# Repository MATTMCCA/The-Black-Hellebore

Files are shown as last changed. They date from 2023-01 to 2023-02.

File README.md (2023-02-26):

# The Black Hellebore

### The Black Hellebore, RK61 PCB (Redesign)

What to do with the most popular keyboard on amazon? Reverse engineer it obviously! QMK powered PCB for the RK61. The design uses actual STM32 IC.

**The PCB design in this repository is not intended for commercial sales**

---

* **[Watch the Hand Assembly Video : PART I](https://youtu.be/cKcGKz691ds)**
* **[Watch the Hand Assembly Video : PART II](https://youtu.be/HiYZSflaqEU)**
* **[Watch the Solder Joint Repair Video : PART III](https://youtu.be/VTa4d78aN-c)**
* **[Watch Load Switch Demo](https://youtu.be/AGMwodDWTGg)**

---

## Understanding USB 2.0 Power Spec.

[In general, the specifications for a USB 1.0 and 2.0 standard downstream port, delivers up to 500 mA or 0.5A.](https://resources.pcb.cadence.com/blog/2020-what-are-the-maximum-power-output-and-data-transfer-rates-for-the-usb-standards) With this statement it becomes clear, the max power available to any system using a **type A** connector is 500mA. If the host implements brick-wall current limiting, and the device attached attempts to draw more than 2.5Watts, the current limiter will start dissipating heat. This dissipated heat can lead to thermal shutdown and or possible damage to the host system.

Building on this further, it makes since why most USB type A ports provide more than 500mA. Its to prevent the host current limiting circuit from going into thermal shutdown.

*because I don't have mechanisms in place on the device to handle power negotiation, I'm not assuming the host port can supply more than 2.5Watts of power*

*I would also like to briefly point out that the STM32L412 only has USB Full speed 2.0. It seems kinda silly to use a USB 3.0 connector, when both power and data are USB gen 2.0, admittedly it is nice not worrying about the cable orientation.*

## Part Notes

* CC1 & CC2 Resistors should be 1% not 5%.
* SK6803MINI-E is recommended over SK6812MINI-E.

## Project State

* My Digikey order has arrived.
* Waiting on PCB's (ETA Jan 20th) - Arrived 1-8-2023
* Finished final hand assembly (1-21-2023)
* Tested and confirmed working with QMK and VIA.
* Figured out all of the things (duration, too long...)
* Board Revision Pending.... 
* Board Rev Finished (1-28-2023, sent to fab)
* Waiting on PCB's (ETA 2-10-2023) - Arrived 2-6-2023
* Started finial hand assembly (2-11-2023) (see project log below) 
* Board Revision Pending.... 
* Sent version 1.2.1 to fab
* Got 1.2.1 from fab, all is well
* Inadvertently filmed a time laps (2-22-2023)
* non time laps video pending.
* Project done, the PCB works perfect!

*My fancy USB cable reported a 1.5Watt power draw before the load switch went into auto recover. This tells me, my current limit is actually set to around 300mA, not 445mA as calculated.*

# Project Log

### Epic Fail
I began soldering the MCU and current switch IC and everything was going smooth. After I soldered the first row of LED's, I applied power and nothing happened. It was at this point I began to suspect my clever feedback network, sure enough I was getting zero volts on the output. 

Without a second thought, I depopulated the retry network and tested the circuit again. Same result, no RGB. I started measuring the RGB PWM of the MCU with my scope, I was getting no PWM output, I thought "Great! I zapped my STM32". I removed power from the circuit, then started poking around with my meter, come to find out, every RGB LED was shorted to ground.

I removed all of the RGB LED's and checked the first row of pads, no shorts. I replaced the LED, and there's a short!! I tried 5 different LED's before I noticed it..... JLCPCB milled into the ground pore copper!!!! see **001.bmp & 002.bmp**. When the LED is soldered, a short occurs between the pin and the ground plane. I'm wondering if this issue affected previous revs.

I'm going to add a keep out area around the RGB LED's to prevent my future revision from suffering the same fate as 1.2.0. .....that's another punch to the wallet, I'm not making that mistake again.... I also expected better milling from JLCPCB.

### A Small Win
From what I can tell, the auto retry feedback network on the ```AP22653AW6-7``` worked as designed. When a fault occurs, oscillation takes place in the feedback network. When the short is removed the enable signal stays high, it was neat to see it in action for the first time on the scope.

---

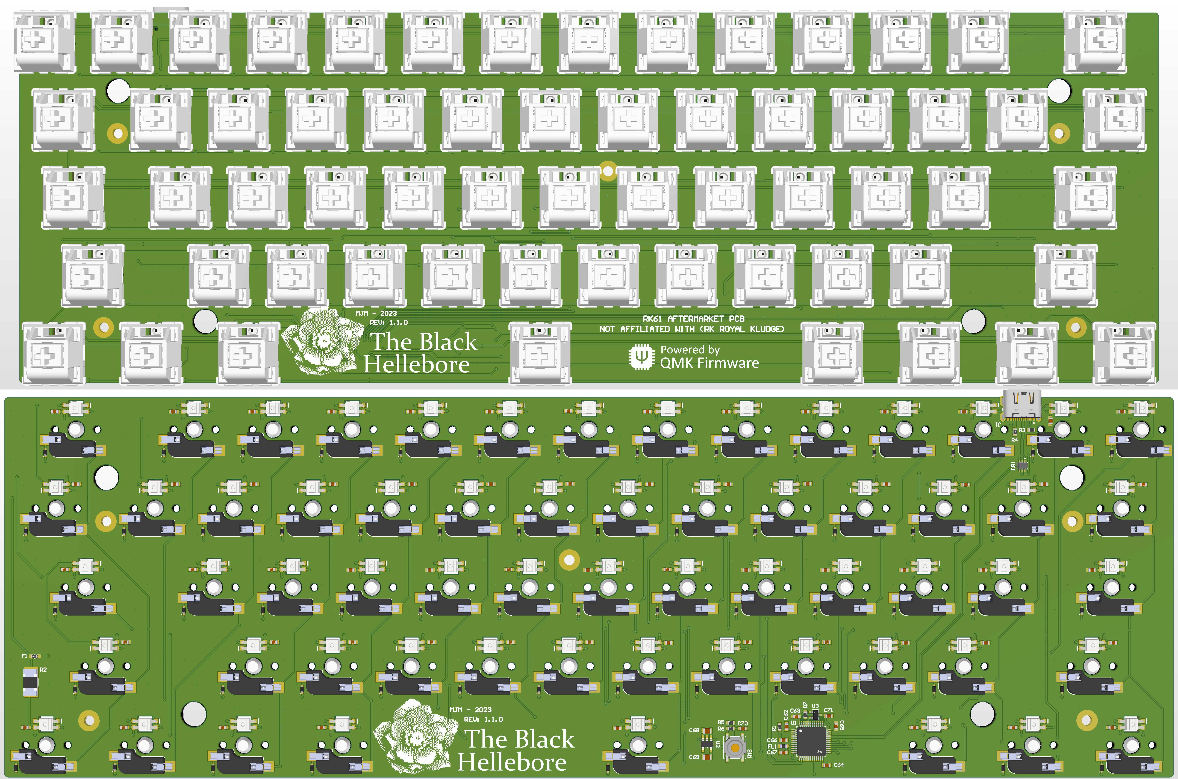
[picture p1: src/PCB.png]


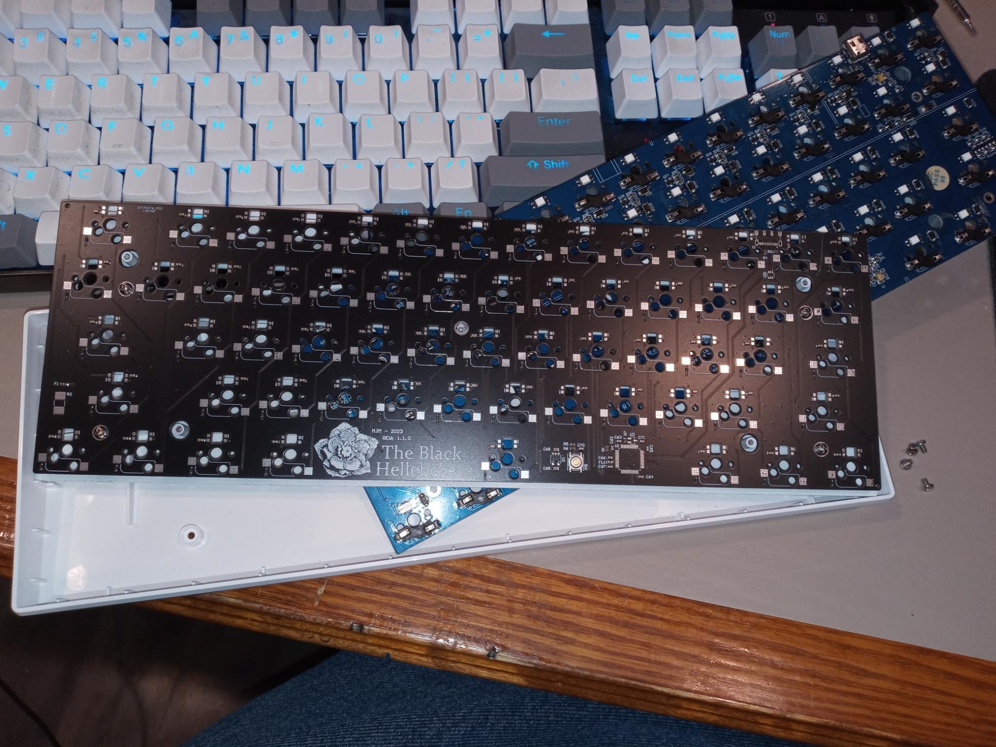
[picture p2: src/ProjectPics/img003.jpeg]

 
# View All Project Files Online
 
https://www.altium.com/viewer/

---
 
MIT licensed keyboard.

"Buy Me A Coffee" (https://www.buymeacoffee.com/mccardlema3)

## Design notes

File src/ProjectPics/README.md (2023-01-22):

# The Black Hellebore

### The Black Hellebore, RK61 PCB (Clone)

* IMG001 (1000x switch sockets and 1000x RGB LEDS)
* IMG002 (Digikey Parts Order)
* IMG003 (JLC PCB's arrived)
* IMG004 (preliminary aftermarket fit)
* IMG005 (fully assembled PCB attached to RK61 plate)
* IMG006 (fully assembled PCB in RK61 case)
* IMG007 (playing with RGB)

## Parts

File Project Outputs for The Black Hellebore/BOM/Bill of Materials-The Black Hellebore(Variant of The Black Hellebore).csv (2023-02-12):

Comment | Description | Designator | Footprint | LibRef | Quantity
CC0603JRX7R9BB104 | 0603 0.1 uF 50 V ±5 % Tolerance X7R SMT Multilayer Ceramic Capacitor | C1, C2, C3, C4, C5, C6, C7, C8, C9, C10, C11, C12, C13, C14, C15, C16, C17, C18, C19, C20, C21, C22, C23, C24, C25, C26, C27, C28, C29, C30, C31, C32, C33, C34, C35, C36, C37, C38, C39, C40, C41, C42, C43, C44, C45, C46, C47, C48, C49, C50, C51, C52, C53, C54, C55, C56, C57, C58, C59, C60, C61, C62, C63, C64, C65, C66, C67, C69, C70, C71 | FP-CC0603-DA-MFG | CMP-004-000009-6 | 70
GRM21BR71A106KA73K | Cap Ceramic 10uF 10V X7R 10% Pad SMD 0805 125C T/R | C68, C72 | FP-GRM21B-0_15-MFG | CMP-004-000013-3 | 2
CC0603JRX7R7BB105 | Cap Ceramic 1uF 16V X7R 5% SMD 0603 125°C Paper T/R | C73 | FP-CC0603-DA-MFG | CMP-004-000010-4 | 1
RCLAMP0504FBTCT | ESD Suppressor TVS Quad Uni-Dir 30kV 6-Pin SC-70 T/R | CR1 | SC70_RCLAMP_SEM | CMP-138-000000-2 | 1
RB520S30T5G | RB520S30T5G - 30 V 200 mA Surface Mount Schottky Diode - SOD-523 | D1, D2, D3, D4, D5, D6, D7, D8, D9, D10, D11, D12, D13, D14, D15, D16, D17, D18, D19, D20, D21, D22, D23, D24, D25, D26, D27, D28, D29, D30, D31, D32, D33, D34, D35, D36, D37, D38, D39, D40, D41, D42, D43, D44, D45, D46, D47, D48, D49, D50, D51, D52, D53, D54, D55, D56, D57, D58, D59, D60, D61, D62 | ONSC-SOD-523-2-502-01_V | CMP-070-000008-4 | 62
0603L010YR | 15VDC 100mA | F1 | FP-0603L-MFG | CMP-096-000003-1 | 1
BLM18AG601SN1D | 600 Ohms @ 100MHz 1 Ferrite Bead 0603 _1608 Metric_ 500mA 380mOhm | FL1 | BEADC1608X95N | CMP-032-000000-2 | 1
DX07S016JA1R1500 | Connector, USB Type C Receptacle, 1500 piece reel, 16 Pin Version | J1 | FP-DX07S016JA1R1500-MFG | CMP-042-000007-2 | 1
RMCF0603JT10K0 | Res Thick Film 0603 10K Ohm 5% 1/10W ±100ppm/°C Molded SMD SMD Paper T/R | R1, R2, R5, R7 | FP-RMCF0603-MFG | CMP-012-000009-4 | 4
RMCF0603JT5K10 | Res Thick Film 0603 5.1K Ohm 5% 1/10W ±200ppm/°C Molded SMD Paper T/R | R3, R4 | FP-RMCF0603-MFG | CMP-012-000000-2 | 2
RMCF0603JT1K00 | Res Thick Film 0603 1K Ohm 5% 1/10W ±200ppm/°C Molded SMD Paper T/R | R6 | FP-RMCF0603-MFG | CMP-000007-3 | 1
RMCF0603JT100K | Res Thick Film 0603 100K Ohm 5% 1/10W ±200ppm/°C Molded SMD Paper T/R | R8 | FP-RMCF0603-MFG | CMP-000004-8 | 1
RMCF0603FT68K0 | Res Thick Film 0603 68K Ohm 1% 0.1W(1/10W) ±100ppm/C Pad SMD Automotive T/R | R9 | FP-RMCF0603-MFG | CMP-012-000019-2 | 1
PTS526SK15SMTR2LFS | Switch Tactile N.O. SPST Round Button Gull Wing 0.05A 12VDC 200000Cycles 2.55N SMD T/R | SW1 | FP-PTS526SK15SMTR2LFS-MFG | CMP-014-000000-1 | 1
STM32L412CBT6 | STMICROELECTRONICS - STM32L412CBT6 - ARM MCU, STM32 Family STM32L4 Series Microcontrollers, ARM Cortex-M4, 32bitu, 80 MHz, 128 KB, 40 KB | U1 | FP-LQFP48-5B-MFG | CMP-148-000005-1 | 1
AP2139AK-3.3TRG1 | IC REG LDO 3.3V 0.25A SOT25 | U2 | DBV0005A-IPC_A | CMP-140-000002-1 | 1
MIC803-26D4VC3-TR | 3-Pin Microprocessor Supervisor Circuit w/ Open-Drain Reset Output | U3 | SC-70_C3_MCH | CMP-136-000000-2 | 1
AP22653AW6-7 | PRECISION ADJUSTABLE CURRENT-LIMITED POWER SWITCHES, -40 to 85°C pF, RoHS | U4 | SOT26-A1_DIO | CMP-148-000002-2 | 1

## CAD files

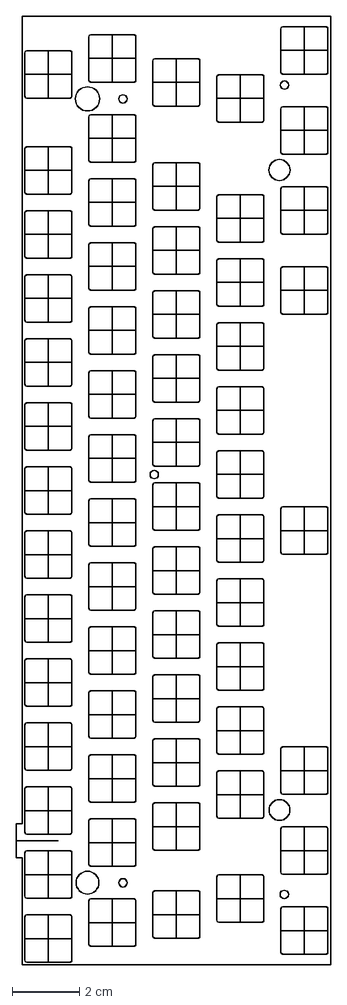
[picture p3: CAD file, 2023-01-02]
Factory_19.05mm/Fixed-Factory-Template.dxf
9.35 x 28.2 cm

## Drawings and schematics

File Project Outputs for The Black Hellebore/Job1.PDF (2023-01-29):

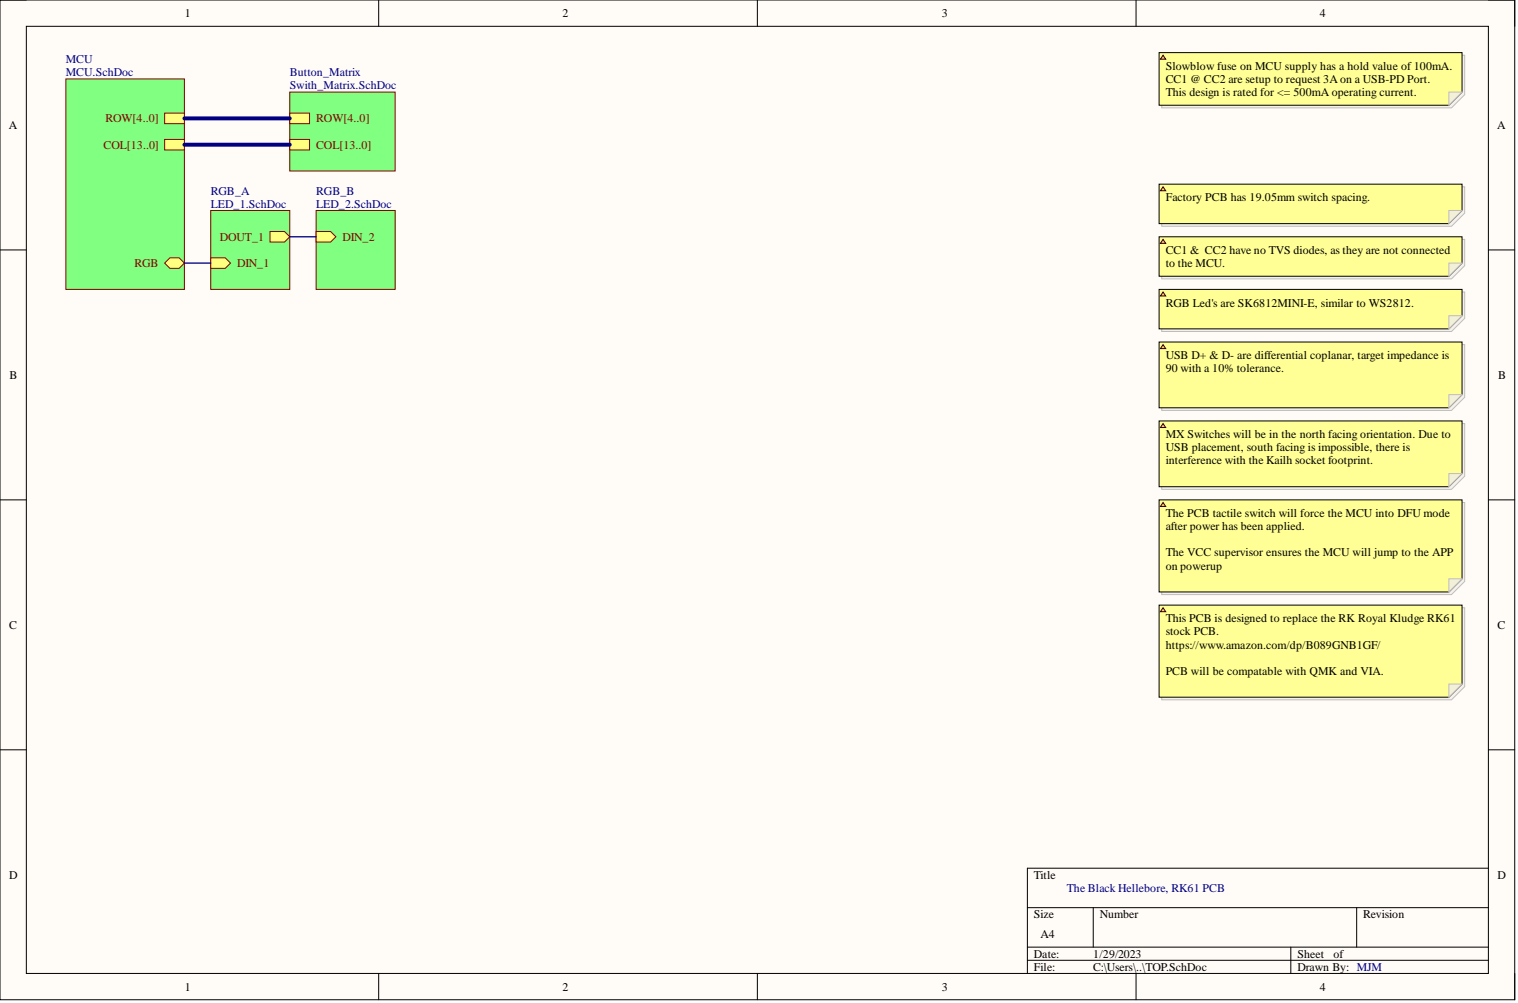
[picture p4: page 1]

Slowblow fuse on MCU supply has a hold value of 100mA.
CC1 @ CC2 are setup to request 3A on a USB-PD Port.
This design is rated for <= 500mA operating current.

Factory PCB has 19.05mm switch spacing.

CC1 & CC2 have no TVS diodes, as they are not connected
to the MCU.

RGB Led's are SK6812MINI-E, similar to WS2812.

USB D+ & D- are differential coplanar, target impedance is
90 with a 10% tolerance.

MX Switches will be in the north facing orientation. Due to
USB placement, south facing is impossible, there is
interference with the Kailh socket footprint.

The PCB tactile switch will force the MCU into DFU mode
after power has been applied.

The VCC supervisor ensures the MCU will jump to the APP
on powerup

This PCB is designed to replace the RK Royal Kludge RK61
stock PCB.
https://www.amazon.com/dp/B089GNB1GF/

PCB will be compatable with QMK and VIA.

Title
The Black Hellebore, RK61 PCB

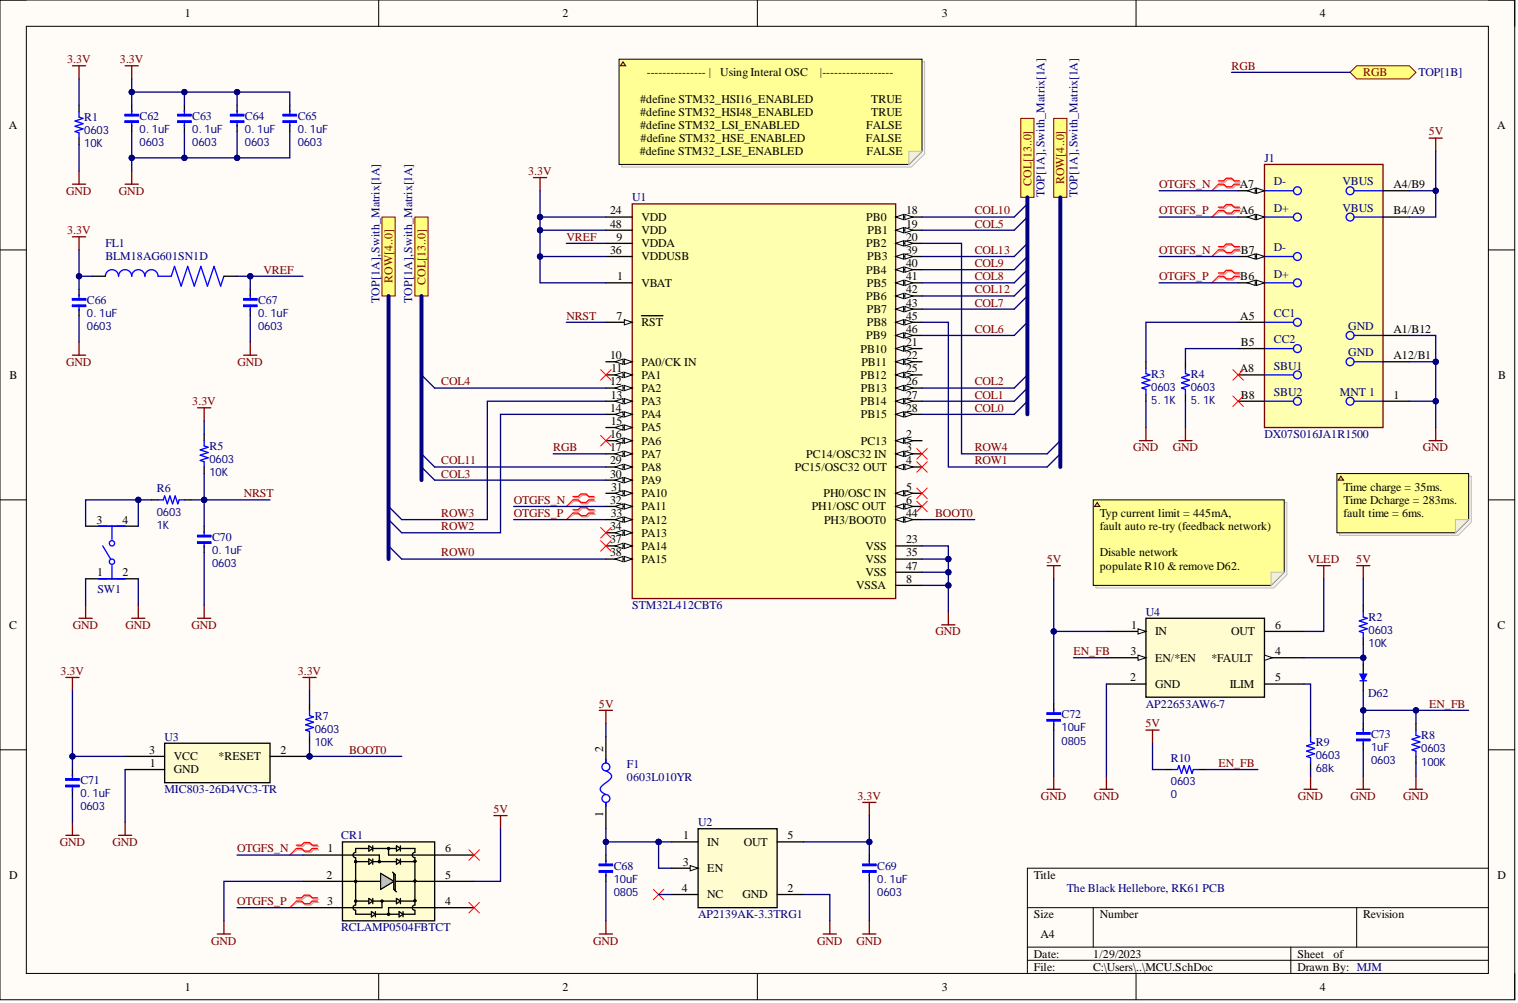
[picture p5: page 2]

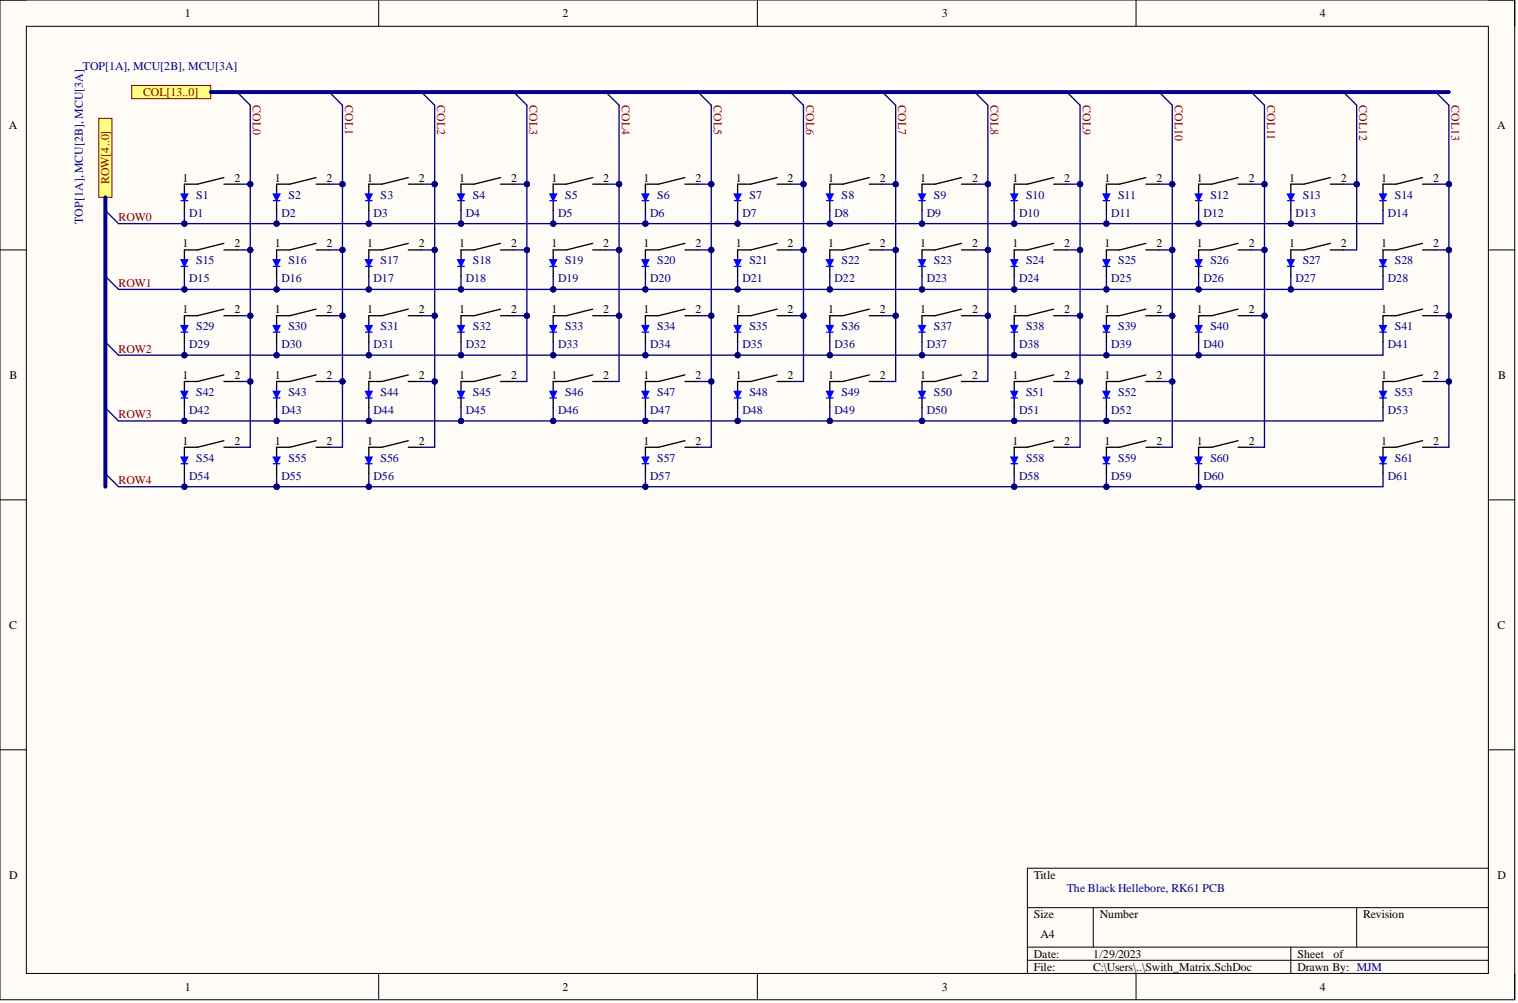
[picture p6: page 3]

Title
The Black Hellebore, RK61 PCB

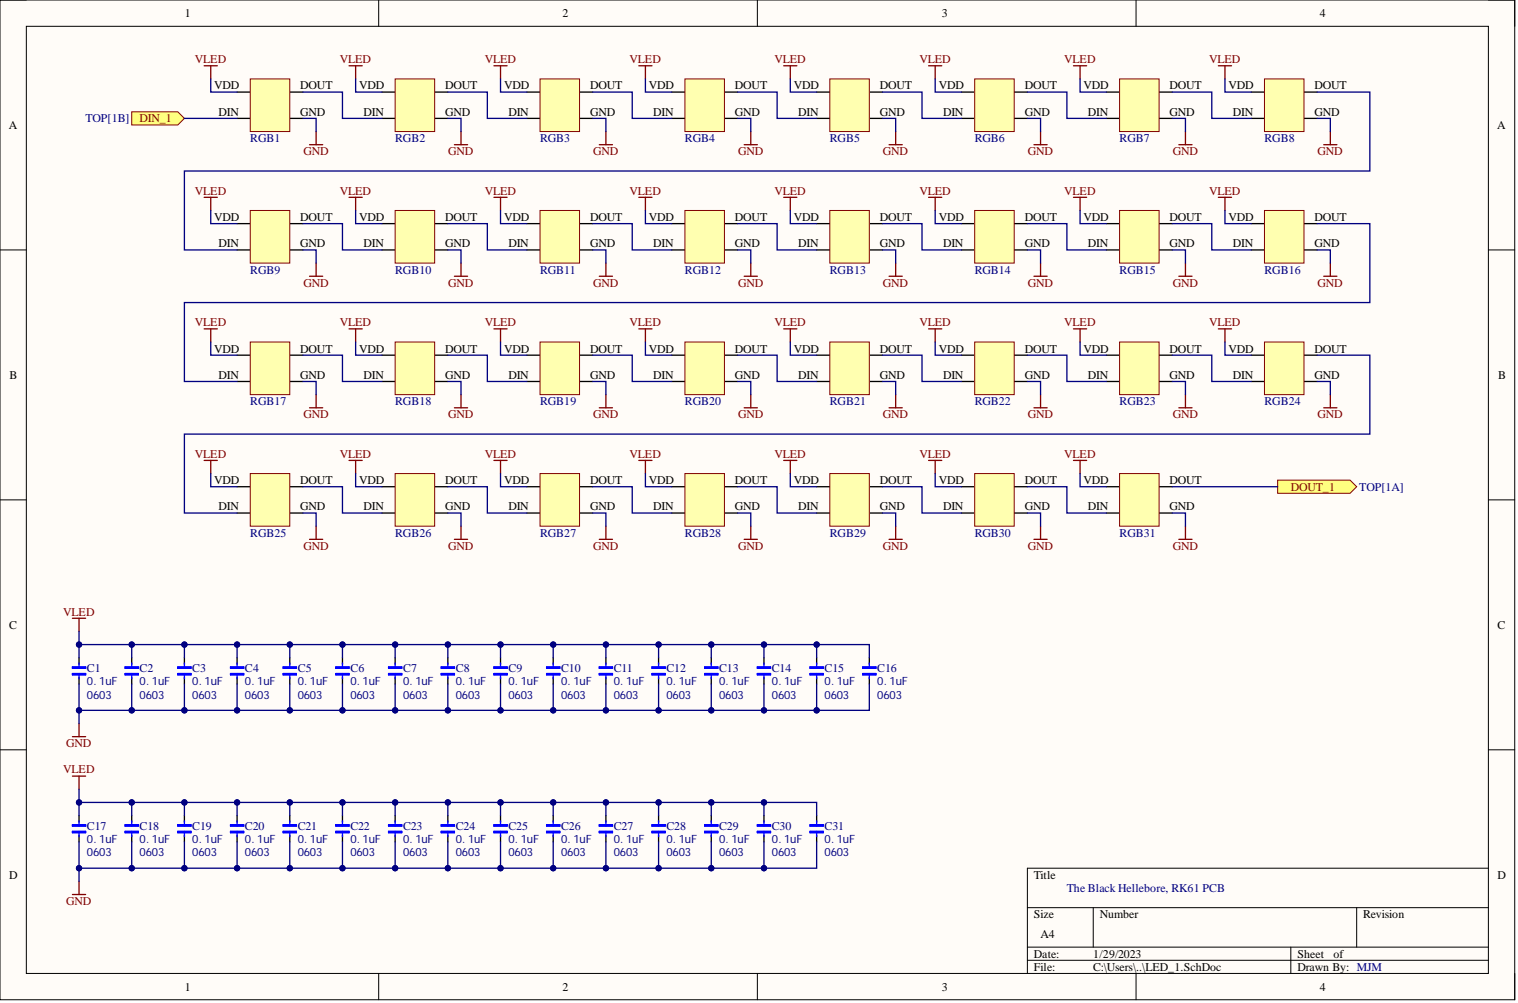
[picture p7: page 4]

Title
The Black Hellebore, RK61 PCB

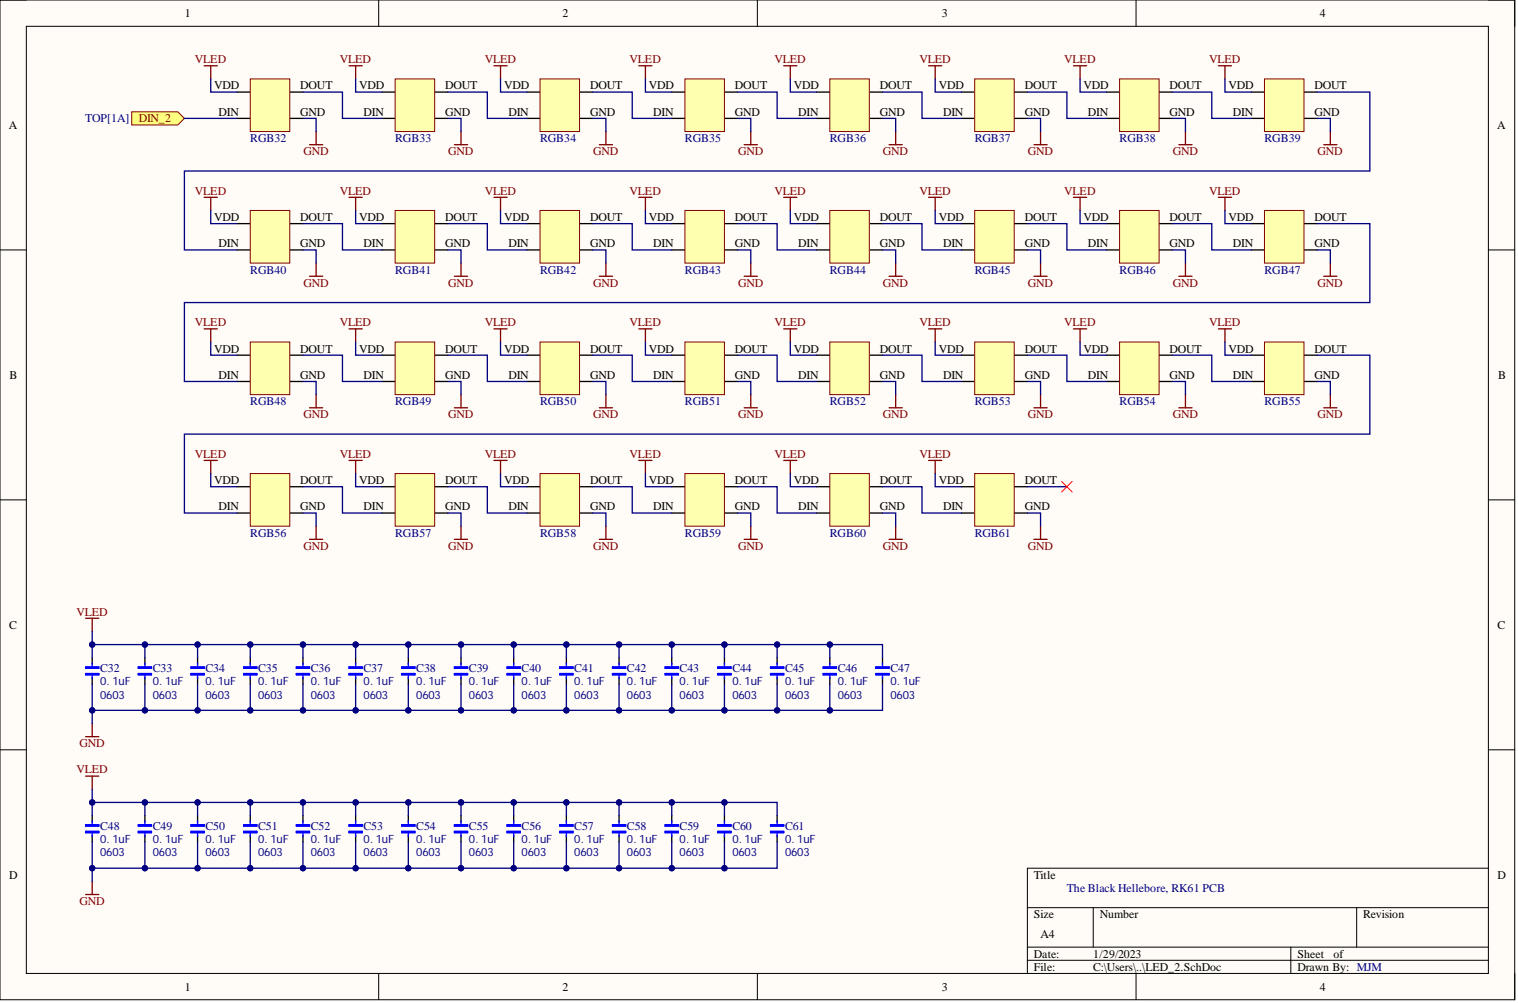
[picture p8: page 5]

Title
The Black Hellebore, RK61 PCB

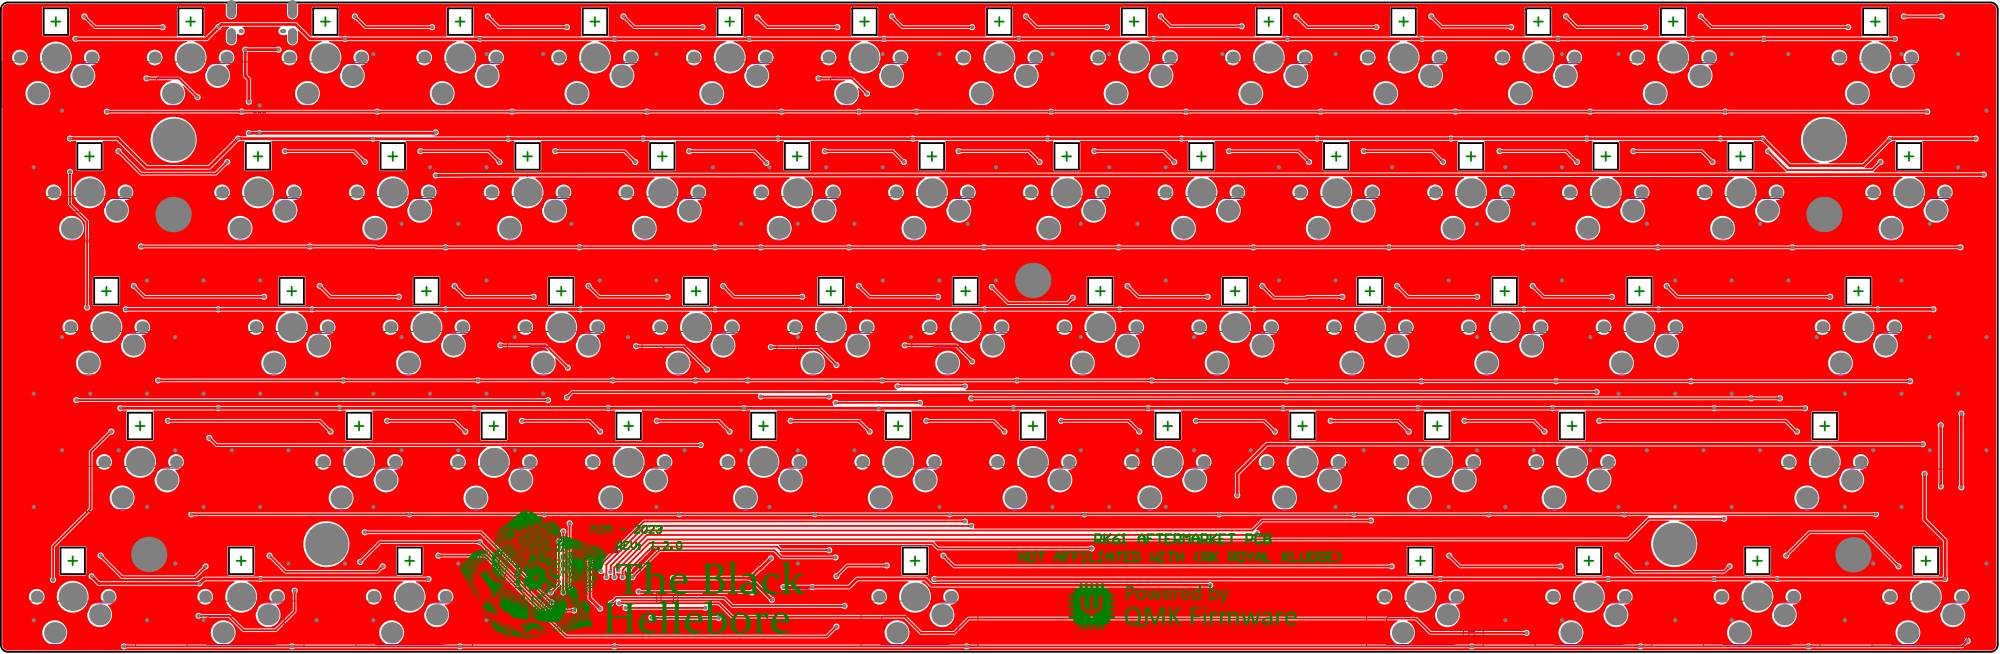
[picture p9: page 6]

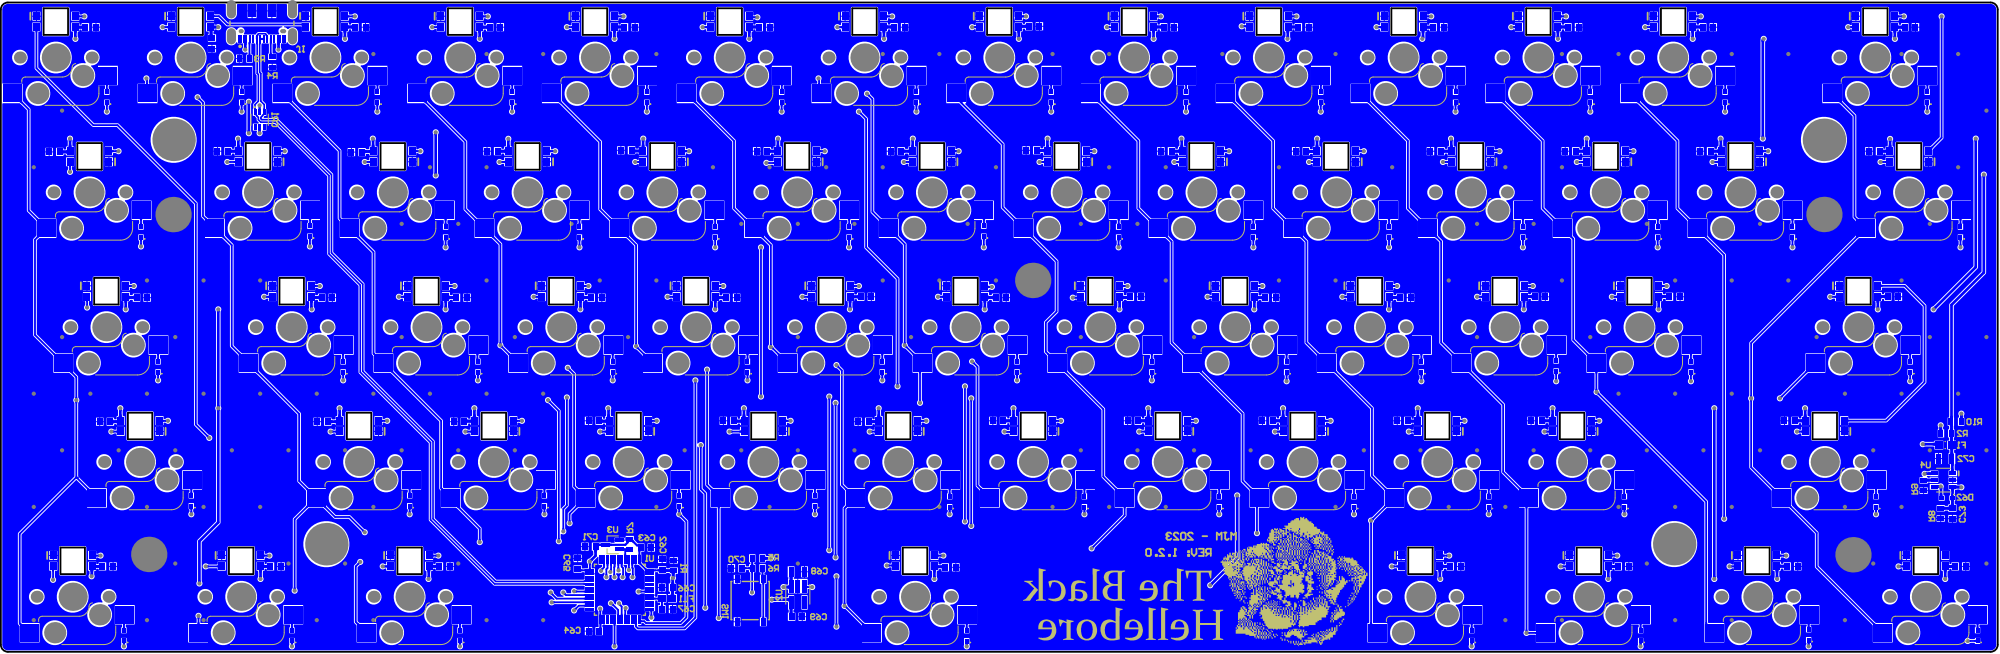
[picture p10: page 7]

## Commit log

2022-12-31 project upload
    [Bill of Materials-The Black Hellebore.csv, Factory Template v1.dxf, LED_1.SchDoc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]
2022-12-31 bad trace
    I found a nub, removed and re-exported.
    [LED_1.SchDoc, LED_2.SchDoc, MCU.SchDoc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]
2023-01-01 project update
    Sent to fab!
    Changed board outline to include RGB milling.
    Added CPL for JLCPCB.
    Added BOM for JLCPCB.
    Added BOM for digikey (not all parts were in stock at LCSC) some assembly by "me" will be needed.
    [BOM_DIGIKEY.xlsx, BOM_JLCSMT.xlsx, LED_1.SchDoc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]
2023-01-01 Create low volume commercialization.xlsx
    Create a quick projection to estimate the cost of commercialization on Tindie.
    At low volume, it makes no sense....
    [low volume commercialization.xlsx]
2023-01-02 PCB Update
    I made a grave mistake while measuring switch placement. As it turns out its actually 19.05mm, as a result, I have updated the project files. I also have to send everything off to fab again. YAY! expensive mistakes are the best kind! measure twice, then twice again!
    [Factory Template v1.dxf, Fixed-Factory-Template.dxf, LED_1.SchDoc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]
2023-01-02 high resolution scans.
    added high resolution scans of pcb top and plate, using jpg compression to save space.
2023-01-03 nexus!!!
    Apparently, one needs to file with every state in which one has a nexus.... so I'm not selling anything lol... Plus I don't feel like creating an LLC, even though that would be awesome.
    [low volume commercialization.xlsx]
2023-01-03 Fixed Schematic warning about floating nets.
    I ran the bus wrong. Its fixed, this change wont affect the board files.
    [LED_1.SchDoc, LED_2.SchDoc, MCU.SchDoc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]
2023-01-22 updated readme to reflect current thinking
2023-01-23 Update README.md
    I don't think the current mirror would solve anything. I would still have 5v @ 480mA to play with. the drop over the red led would still be the path of least resistance.
2023-01-28 Board Rev
    I removed the series resistor and replaced it with a current limited load switch.
    [BOM_DIGIKEY.xlsx, BOM_JLCSMT.xlsx, Bill of Materials-The Black Hellebore.csv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]
2023-01-29 Update README.md
    I guess its not a clone, its a redesign of the pcb. Only the pcb dimensions, mounting holes and usb placement are the same.
2023-02-12 project update
    Added copper keepout around the RGB LED's, added Fiducial markers on bottom layer. Removed not fitted parts in CPL file. compressed epic fail images with png vs bmp.
    [BOM_JLCSMT.xlsx, Bill of Materials-The Black Hellebore(Variant of The Black Hellebore).csv, Bill of Materials-The Black Hellebore.csv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]
2023-02-12 Update README.md
    sent to fab *fingers crossed*
